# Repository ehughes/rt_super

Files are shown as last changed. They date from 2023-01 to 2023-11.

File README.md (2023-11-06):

# RT685 SuperMonkey- Hardware #

This repo has the PCB design data for the SuperMonkey that is based upon the i.MXRT685 in a VFBGA176 package.  This design was created to show a minimal configuration example of the i.MXRT685 using QSPI flash on FlexSPI port A.    Each PCB revision is in its own folder.  I typically always keep copies of all revisions in one repo so I can have access to multiple CCA versions at one time (instead of branches for each PCB/CCA).   Branches are used for development and merged into master when boards are sent out.

The SuperMonkey is in a prototype state.   Use at your own risk.

### Latest Revision - Navigation ###

The revisions is are PCB Rev B1 and PCB Rev C. 

Rev C is a new formfactor with more pins and integrated OCTAL PSRAM

The design files are in Altium v21 format.

### History/Notes

#### PCB REV B:

- 1st official prototype.   Rev A was dispositioned.

#### PCB REV B:

- 1st official prototype.   Rev A was dispositioned.

#### PCB REV B1:

- Minor Fix to the I2C PMIC Interface
- Font Fixes

#### PCB REV C:

- New Form Factor MK-76 PGA
- No Onboard flash.  Octal PSRA<>

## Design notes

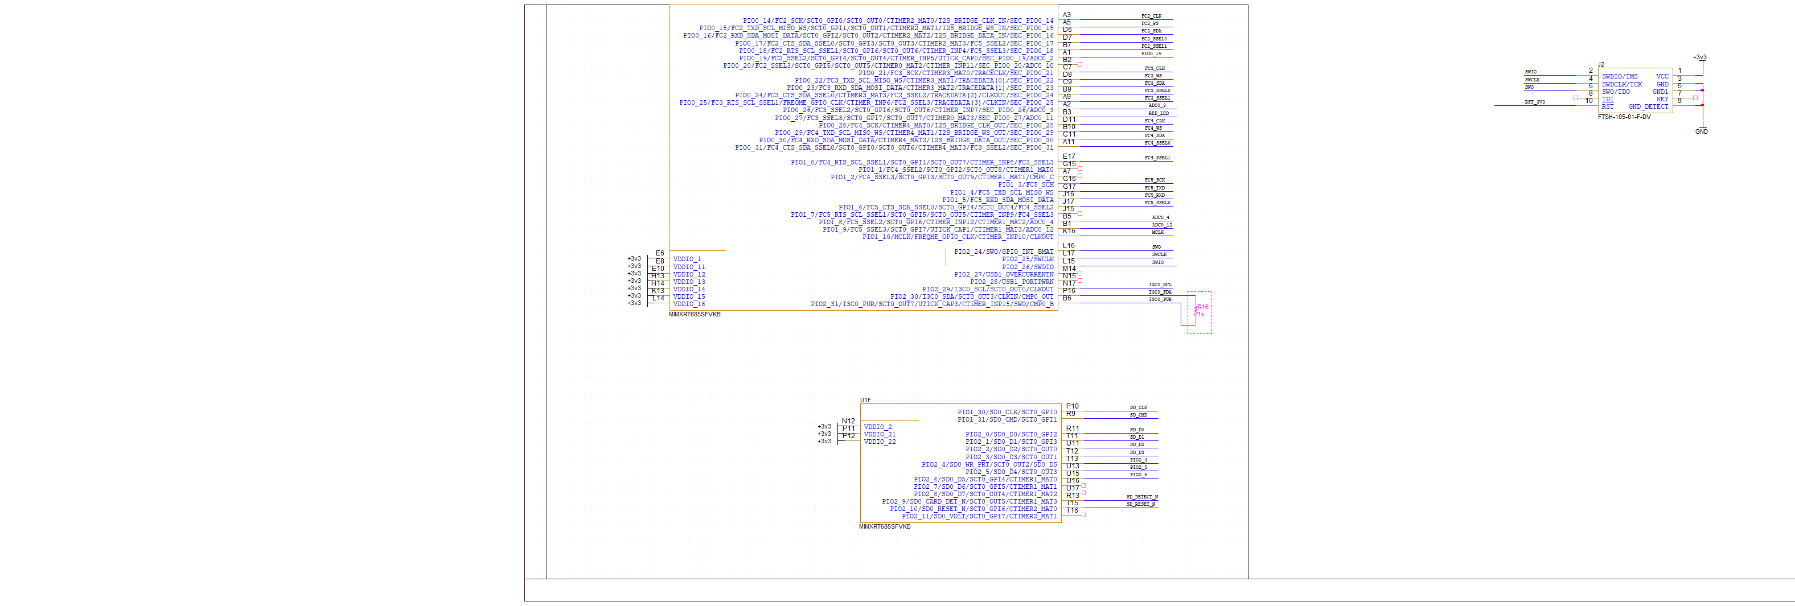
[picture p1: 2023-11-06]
PCB REV C/out/RT_SUPER_C.png

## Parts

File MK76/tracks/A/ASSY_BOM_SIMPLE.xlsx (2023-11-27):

 |  |  |  | Assembly BOM | Field=CCA_PART_NUMBER
 |  |  |  | Rev: | Field=VariantName
 |  |  |  | Description: | Field =PROJECT_TITLE_LINE_1
Column = Fitted | Column = Line # | Column=Quantity | Column=Designator | Column=Description | Column=Manufacturer | Column=Manufacturer Part Number | Column = Substitution Notes

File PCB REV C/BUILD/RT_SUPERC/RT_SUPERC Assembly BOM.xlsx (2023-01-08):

 |  |  |  | Assembly BOM | RT_SUPER
 |  |  |  | Rev: | C
 |  |  |  | Description: | RT_SUPER
Fitted | Line # | Quantity | Designator | Description | Manufacturer | Manufacturer Part Number | Substitution Notes
Fitted | 1 | 3 | C1, C5, C18 | CAP CER 2.2UF 6.3V X7R 0603 | Murata Electronics | GCM188R70J225KE22D | 2.2µF , 6.3V , ±10% , X7R , -55°C ~ 125°C , AEC-Q200 , 0603
Fitted | 2 | 2 | C2, C42 | CAP CER 4.7UF 6.3V X7S 0603 | Murata Electronics | GCJ188C70J475KE02D | 4.7µF , 6.3V , ±10% , X7S , -55°C ~ 125°C , AEC-Q200 , 0603
Fitted | 3 | 1 | C3 | CAP CER 0.47UF 25V X5R 0402 | Murata Electronics | GRT155R61E474KE01D | 0.47µF , 25V , ±10% , X5R , -55°C ~ 85°C , AEC-Q200 , 0402
Fitted | 4 | 3 | C4, C8, C10 | CAP CER 1UF 10V X7S 0402 | Murata Electronics | GCM155C71A105KE38D | 1µF , 10V , ±10% , X7S , -55°C ~ 125°C , AEC-Q200 , 0402
Fitted | 5 | 29 | C6, C12, C13, C14, C15, C16, C17, C20, C21, C22, C23, C24, C25, C26, C27, C28, C29, C30, C31, C32, C33, C34, C35, C36, C37, C38, C39, C40, C41 | Cap Ceramic 0.1uF 6.3VDC X5R 10% SMD 0201 Paper T/R | Yageo | CC0201KRX5R5BB104
Fitted | 6 | 2 | C7, C9 | CAP CER 10UF 10V X5R 0603 | Murata Electronics | GRT188R61A106ME13D | 10µF , 10V , ±20% , X5R , -55°C ~ 85°C , AEC-Q200 , 0603
Fitted | 7 | 2 | C11, C19 | CAP CER 18PF 50V C0G 0402 | TDK Corporation | CGA2B2C0G1H180J050BA | 18pF , 50V , ±5% , C0G, NP0 , -55°C ~ 125°C , AEC-Q200 , 0402
Fitted | 8 | 1 | C43 | CAP CER 0.1UF 16V X7R 0402 | TDK Corporation | CGA2B1X7R1C104K050BC | 0.1µF , 16V , ±10% , X7R , -55°C ~ 125°C , AEC-Q200 , 0402
Fitted | 9 | 2 | C44, C45 | CAP CER 9.5PF 50V C0G/NP0 0402 | Murata Electronics | GCQ1555C1H9R5BB01D | 9.5pF , 50V , ±0.1pF , C0G, NP0 , -55°C ~ 125°C , AEC-Q200 , 0402
Fitted | 10 | 2 | D1, D2 | DIODE SCHOTTKY 30V 1A SOD323 | Diodes Inc | BAT760-7
Fitted | 11 | 1 | D3 | LED 1.6X0.8MM 570NM GRN CLR SMD | Kingbright Corp | APT1608CGCK
Fitted | 12 | 1 | D4 | LED 1.6X0.8MM 630NM RED CLR SMD | Kingbright Corp | APT1608SURCK
Fitted | 13 | 1 | J2 | SAMTEC - FTSH-105-01-F-DV - .050 X .050 | SAMTEC | FTSH-105-01-F-DV
Fitted | 14 | 2 | L2, L3 | Inductor 2.2µH 1.5A | Taiyo Yuden | NRH3012T2R2MN
Fitted | 15 | 1 | R1 | RES 10K OHM 1/10W 1% 0402 SMD | Panasonic Electronic Components | ERJ-2RKF1002X | 10k , ±1% , 0402 , AEC-Q200
Fitted | 16 | 2 | R2, R5 | RES 20K OHM 1/10W 1% 0402 SMD | Panasonic Electronic Components | ERJ-2RKF2002X | 20k , ±1% , 0402 , AEC-Q200
Fitted | 17 | 2 | R3, R4 | RES 2.2K OHM 1/10W 1% 0402 SMD | Panasonic Electronic Components | ERJ-2RKF2201X | 2.2k , ±1% , 0402 , AEC-Q200
Fitted | 18 | 6 | R6, R7, R10, R11, R21, R22 | RES 0.0 OHM 1/10W JUMP 0402 SMD | Panasonic Electronic Components | ERJ-2GE0R00X | 0 , Jumper , 0402 , AEC-Q200
Fitted | 19 | 5 | R8, R9, R12, R13, R14 | RES 100K OHM 1/10W 1% 0402 SMD | Panasonic Electronic Components | ERJ-2RKF1003X | 100k , ±1% , 0402 , AEC-Q200
Not Fitted | 19 | 0 | R15, R17, R18 | RES 100K OHM 1/10W 1% 0402 SMD | Panasonic Electronic Components | ERJ-2RKF1003X | 100k , ±1% , 0402 , AEC-Q200
Fitted | 20 | 3 | R16, R19, R20 | RES 1K OHM 1/10W 1% 0402 SMD | Panasonic Electronic Components | ERJ-2RKF1001X | 1k , ±1% , 0402 , AEC-Q200
Fitted | 21 | 1 | U1 | SOC i.MX ARM Cortex M33 176-Pin VFBGA Tray | NXP Semiconductors | MIMXRT685SFVKB
Fitted | 22 | 1 | U2 | Power Management IC for Low-Power Microcontroller Applications 24-Pin HVQFN | NXP Semiconductors | PCA9420BSAZ
Fitted | 23 | 1 | U3 | IC BUFF NON-INVERT 2.7 V SOT23-5 | Texas Instruments | SN74AUC1G07DBVR
Fitted | 24 | 1 | U4 | TVS DIODE 5.5VWM SOT143B | NXP Semiconductors | PRTR5V0U2X,215
Fitted | 25 | 1 | U6 | 3.3v Double-Data-Rate Octal SPI Xccela PSRAM | AP Memory | APS6408L-3OBM-BA
Fitted | 26 | 1 | X1 | CRYSTAL 32.768KHZ 9PF SMD | NDK | NX3215SA-32.768K-STD-MUA-9
Fitted | 27 | 1 | X2 | CRYSTAL 24.000MHZ 18PF SMD | Abracon Corporation | ABM3-24.000MHZ-B2-T

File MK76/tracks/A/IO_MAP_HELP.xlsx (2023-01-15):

 |  |  |  | ____
 |  |  |  |  | Name | Pin Designator | X1 | Y1 | ObjectKind | Orientation
1 | VREF |  |  |  | VREF | 1 | 0 | 0 | Pin | 0 Degrees
2 | ADC0_8 | PIO0_6 | PIO0_6____ |  | PIO0_6____ADC0_8 | 2 | 0 | -100 | Pin | 0 Degrees
3 | FC0_RXD | PIO0_2 | PIO0_2____ |  | PIO0_2____FC0_RXD | 3 | 0 | -200 | Pin | 0 Degrees
4 | FC0_TXD | PIO0_1 | PIO0_1____ |  | PIO0_1____FC0_TXD | 4 | 0 | -300 | Pin | 0 Degrees
5 | FC0_CLK | PIO0_0 | PIO0_0____ |  | PIO0_0____FC0_CLK | 5 | 0 | -400 | Pin | 0 Degrees
6 | FC0_SSEL0 | PIO0_3 | PIO0_3____ |  | PIO0_3____FC0_SSEL0 | 6 | 0 | -500 | Pin | 0 Degrees
7 | FC0_SSEL1 | PIO0_4 | PIO0_4____ |  | PIO0_4____FC0_SSEL1 | 7 | 0 | -600 | Pin | 0 Degrees
8 | FC1_CLK | PIO0_7 | PIO0_7____ |  | PIO0_7____FC1_CLK | 8 | 0 | -700 | Pin | 0 Degrees
9 | FC1_SSEL0 | PIO0_10 | PIO0_10____ |  | PIO0_10____FC1_SSEL0 | 9 | 0 | -800 | Pin | 0 Degrees
10 | FC1_RXD | PIO0_9 | PIO0_9____ |  | PIO0_9____FC1_RXD | 10 | 0 | -900 | Pin | 0 Degrees
11 | FC1_TXD | PIO0_8 | PIO0_8____ |  | PIO0_8____FC1_TXD | 11 | 0 | -1000 | Pin | 0 Degrees
12 | FC1_SSEL1 | PIO0_11 | PIO0_11____ |  | PIO0_11____FC1_SSEL1 | 12 | 0 | -1100 | Pin | 0 Degrees
13 | HS_SPI_SCK | PIO1_11 | PIO1_11____ |  | PIO1_11____HS_SPI_SCK | 13 | 0 | -1200 | Pin | 0 Degrees
14 | HS_SPI_MISO | PIO1_12 | PIO1_12____ |  | PIO1_12____HS_SPI_MISO | 14 | 0 | -1300 | Pin | 0 Degrees
15 | HS_SPI_MOSI | PIO1_13 | PIO1_13____ |  | PIO1_13____HS_SPI_MOSI | 15 | 0 | -1400 | Pin | 0 Degrees
16 | HS_SPI_SSEL0 | PIO1_14 | PIO1_14____ |  | PIO1_14____HS_SPI_SSEL0 | 16 | 0 | -1500 | Pin | 0 Degrees
17 | ISP0 | PIO1_15 | PIO1_15____ |  | PIO1_15____ISP0 | 17 | 0 | -1600 | Pin | 0 Degrees
18 | ISP1 | PIO1_16 | PIO1_16____ |  | PIO1_16____ISP1 | 18 | 0 | -1700 | Pin | 0 Degrees
19 | ISP2 | PIO1_17 | PIO1_17____ |  | PIO1_17____ISP2 | 19 | 0 | -1800 | Pin | 0 Degrees
20 | FLEXSPI0B_CLK | PIO1_29 | PIO1_29____ |  | PIO1_29____FLEXSPI0B_CLK | 20 | 0 | -1900 | Pin | 0 Degrees
21 | PDM_DATA01 | PIO2_20 | PIO2_20____ |  | PIO2_20____PDM_DATA01 | 21 | 0 | -2000 | Pin | 0 Degrees
22 | PDM_CLK01 | PIO2_16 | PIO2_16____ |  | PIO2_16____PDM_CLK01 | 22 | 0 | -2100 | Pin | 0 Degrees
23 | PDM_DATA23 | PIO2_21 | PIO2_21____ |  | PIO2_21____PDM_DATA23 | 23 | 0 | -2200 | Pin | 0 Degrees
24 | PDM_CLK23 | PIO2_17 | PIO2_17____ |  | PIO2_17____PDM_CLK23 | 24 | 0 | -2300 | Pin | 0 Degrees
25 | PDM_DATA45 | PIO2_22 | PIO2_22____ |  | PIO2_22____PDM_DATA45 | 25 | 0 | -2400 | Pin | 0 Degrees
26 | PDM_CLK45 | PIO2_18 | PIO2_18____ |  | PIO2_18____PDM_CLK45 | 26 | 0 | -2500 | Pin | 0 Degrees
27 | PDM_DATA67 | PIO2_23 | PIO2_23____ |  | PIO2_23____PDM_DATA67 | 27 | 0 | -2600 | Pin | 0 Degrees
28 | PDM_CLK67 | PIO2_19 | PIO2_19____ |  | PIO2_19____PDM_CLK67 | 28 | 0 | -2700 | Pin | 0 Degrees
29 | SD_CMD |  |  |  | SD_CMD | 29 | 0 | -2800 | Pin | 0 Degrees
30 | SD_D0 |  |  |  | SD_D0 | 30 | 0 | -2900 | Pin | 0 Degrees
31 | SD_D1 |  |  |  | SD_D1 | 31 | 0 | -3000 | Pin | 0 Degrees
32 | SD_D2 |  |  |  | SD_D2 | 32 | 0 | -3100 | Pin | 0 Degrees
33 | SD_D3 |  |  |  | SD_D3 | 33 | 0 | -3200 | Pin | 0 Degrees
34 | SD_CLK |  |  |  | SD_CLK | 34 | 0 | -3300 | Pin | 0 Degrees
35 | SD_RESET_N | PIO2_10 | PIO2_10____ |  | PIO2_10____SD_RESET_N | 35 | 0 | -3400 | Pin | 0 Degrees
36 | SD_DETECT_N | PIO2_9 | PIO2_9____ |  | PIO2_9____SD_DETECT_N | 36 | 0 | -3500 | Pin | 0 Degrees
37 | PIO2_4 |  |  |  | PIO2_4 | 37 | 0 | -3600 | Pin | 0 Degrees
38 | PIO2_5 |  |  |  | PIO2_5 | 38 | 0 | -3700 | Pin | 0 Degrees
39 | PIO2_6 |  |  |  | PIO2_6 | 39 | 3000 | 0 | Pin | 0 Degrees
40 | I3C0_SDA |  |  |  | I3C0_SDA | 40 | 3000 | -100 | Pin | 0 Degrees
41 | I3C0_SCL |  |  |  | I3C0_SCL | 41 | 3000 | -200 | Pin | 0 Degrees
42 | FC5_RXD | PIO1_5 | PIO1_5____ |  | PIO1_5____FC5_RXD | 42 | 3000 | -300 | Pin | 0 Degrees
43 | DM_MCU |  |  |  | DM_MCU | 43 | 3000 | -400 | Pin | 0 Degrees
44 | FC5_SSEL0 | PIO1_6 | PIO1_6____ |  | PIO1_6____FC5_SSEL0 | 44 | 3000 | -500 | Pin | 0 Degrees
45 | DP_MCU |  |  |  | DP_MCU | 45 | 3000 | -600 | Pin | 0 Degrees
46 | FC5_TXD | PIO1_4 | PIO1_4____ |  | PIO1_4____FC5_TXD | 46 | 3000 | -700 | Pin | 0 Degrees
47 | FC5_SCK | PIO1_3 | PIO1_3____ |  | PIO1_3____FC5_SCK | 47 | 3000 | -800 | Pin | 0 Degrees
48 | MCLK | PIO1_10 | PIO1_10____ |  | PIO1_10____MCLK | 48 | 3000 | -900 | Pin | 0 Degrees
49 | RST_3V3 |  |  |  | RST_3V3 | 49 | 3000 | -1000 | Pin | 0 Degrees
50 | +3v3 |  |  |  | +3v3 | 50 | 3000 | -1100 | Pin | 0 Degrees
51 | TEMP_SENSE |  |  |  | TEMP_SENSE | 51 | 3000 | -1200 | Pin | 0 Degrees
52 | PMIC_ON |  |  |  | PMIC_ON | 52 | 3000 | -1300 | Pin | 0 Degrees
53 | +VBATT_BU |  |  |  | +VBATT_BU | 53 | 3000 | -1400 | Pin | 0 Degrees
54 | GND |  |  |  | GND | 54 | 3000 | -1500 | Pin | 0 Degrees
55 | +5vUSB |  |  |  | +5vUSB | 55 | 3000 | -1600 | Pin | 0 Degrees
56 | +VBATT |  |  |  | +VBATT | 56 | 3000 | -1700 | Pin | 0 Degrees
57 | +VIN |  |  |  | +VIN | 57 | 3000 | -1800 | Pin | 0 Degrees
58 | FC2_SSEL0 | PIO0_17 | PIO0_17____ |  | PIO0_17____FC2_SSEL0 | 58 | 3000 | -1900 | Pin | 0 Degrees
59 | FC2_SDA | PIO0_16 | PIO0_16____ |  | PIO0_16____FC2_SDA | 59 | 3000 | -2000 | Pin | 0 Degrees
60 | FC2_SSEL1 | PIO0_18 | PIO0_18____ |  | PIO0_18____FC2_SSEL1 | 60 | 3000 | -2100 | Pin | 0 Degrees
61 | FC2_WS | PIO0_15 | PIO0_15____ |  | PIO0_15____FC2_WS | 61 | 3000 | -2200 | Pin | 0 Degrees
62 | FC2_CLK | PIO0_14 | PIO0_14____ |  | PIO0_14____FC2_CLK | 62 | 3000 | -2300 | Pin | 0 Degrees
63 | FC4_SSEL1 | PIO1_0 | PIO1_0____ |  | PIO1_0____FC4_SSEL1 | 63 | 3000 | -2400 | Pin | 0 Degrees
64 | FC4_CLK | PIO0_28 | PIO0_28____ |  | PIO0_28____FC4_CLK | 64 | 3000 | -2500 | Pin | 0 Degrees
65 | FC4_SDA | PIO0_30 | PIO0_30____ |  | PIO0_30____FC4_SDA | 65 | 3000 | -2600 | Pin | 0 Degrees
66 | FC4_SSEL0 | PIO0_31 | PIO0_31____ |  | PIO0_31____FC4_SSEL0 | 66 | 3000 | -2700 | Pin | 0 Degrees
67 | FC4_WS | PIO0_29 | PIO0_29____ |  | PIO0_29____FC4_WS | 67 | 3000 | -2800 | Pin | 0 Degrees
68 | FC3_SSEL0 | PIO0_24 | PIO0_24____ |  | PIO0_24____FC3_SSEL0 | 68 | 3000 | -2900 | Pin | 0 Degrees
69 | FC3_SSEL1 | PIO0_25 | PIO0_25____ |  | PIO0_25____FC3_SSEL1 | 69 | 3000 | -3000 | Pin | 0 Degrees
70 | FC3_SDA | PIO0_23 | PIO0_23____ |  | PIO0_23____FC3_SDA | 70 | 3000 | -3100 | Pin | 0 Degrees
71 | FC3_WS | PIO0_22 | PIO0_22____ |  | PIO0_22____FC3_WS | 71 | 3000 | -3200 | Pin | 0 Degrees
72 | FC3_CLK | PIO0_21 | PIO0_21____ |  | PIO0_21____FC3_CLK | 72 | 3000 | -3300 | Pin | 0 Degrees
73 | ADC0_4 | PIO1_8 | PIO1_8____ |  | PIO1_8____ADC0_4 | 73 | 3000 | -3400 | Pin | 0 Degrees
74 | ADC0_1 | PIO0_12 | PIO0_12____ |  | PIO0_12____ADC0_1 | 74 | 3000 | -3500 | Pin | 0 Degrees
75 | ADC0_3 | PIO0_27 | PIO0_27____ |  | PIO0_27____ADC0_3 | 75 | 3000 | -3600 | Pin | 0 Degrees
76 | ADC0_12 | PIO1_9 | PIO1_9____ |  | PIO1_9____ADC0_12 | 76 | 3000 | -3700 | Pin | 0 Degrees

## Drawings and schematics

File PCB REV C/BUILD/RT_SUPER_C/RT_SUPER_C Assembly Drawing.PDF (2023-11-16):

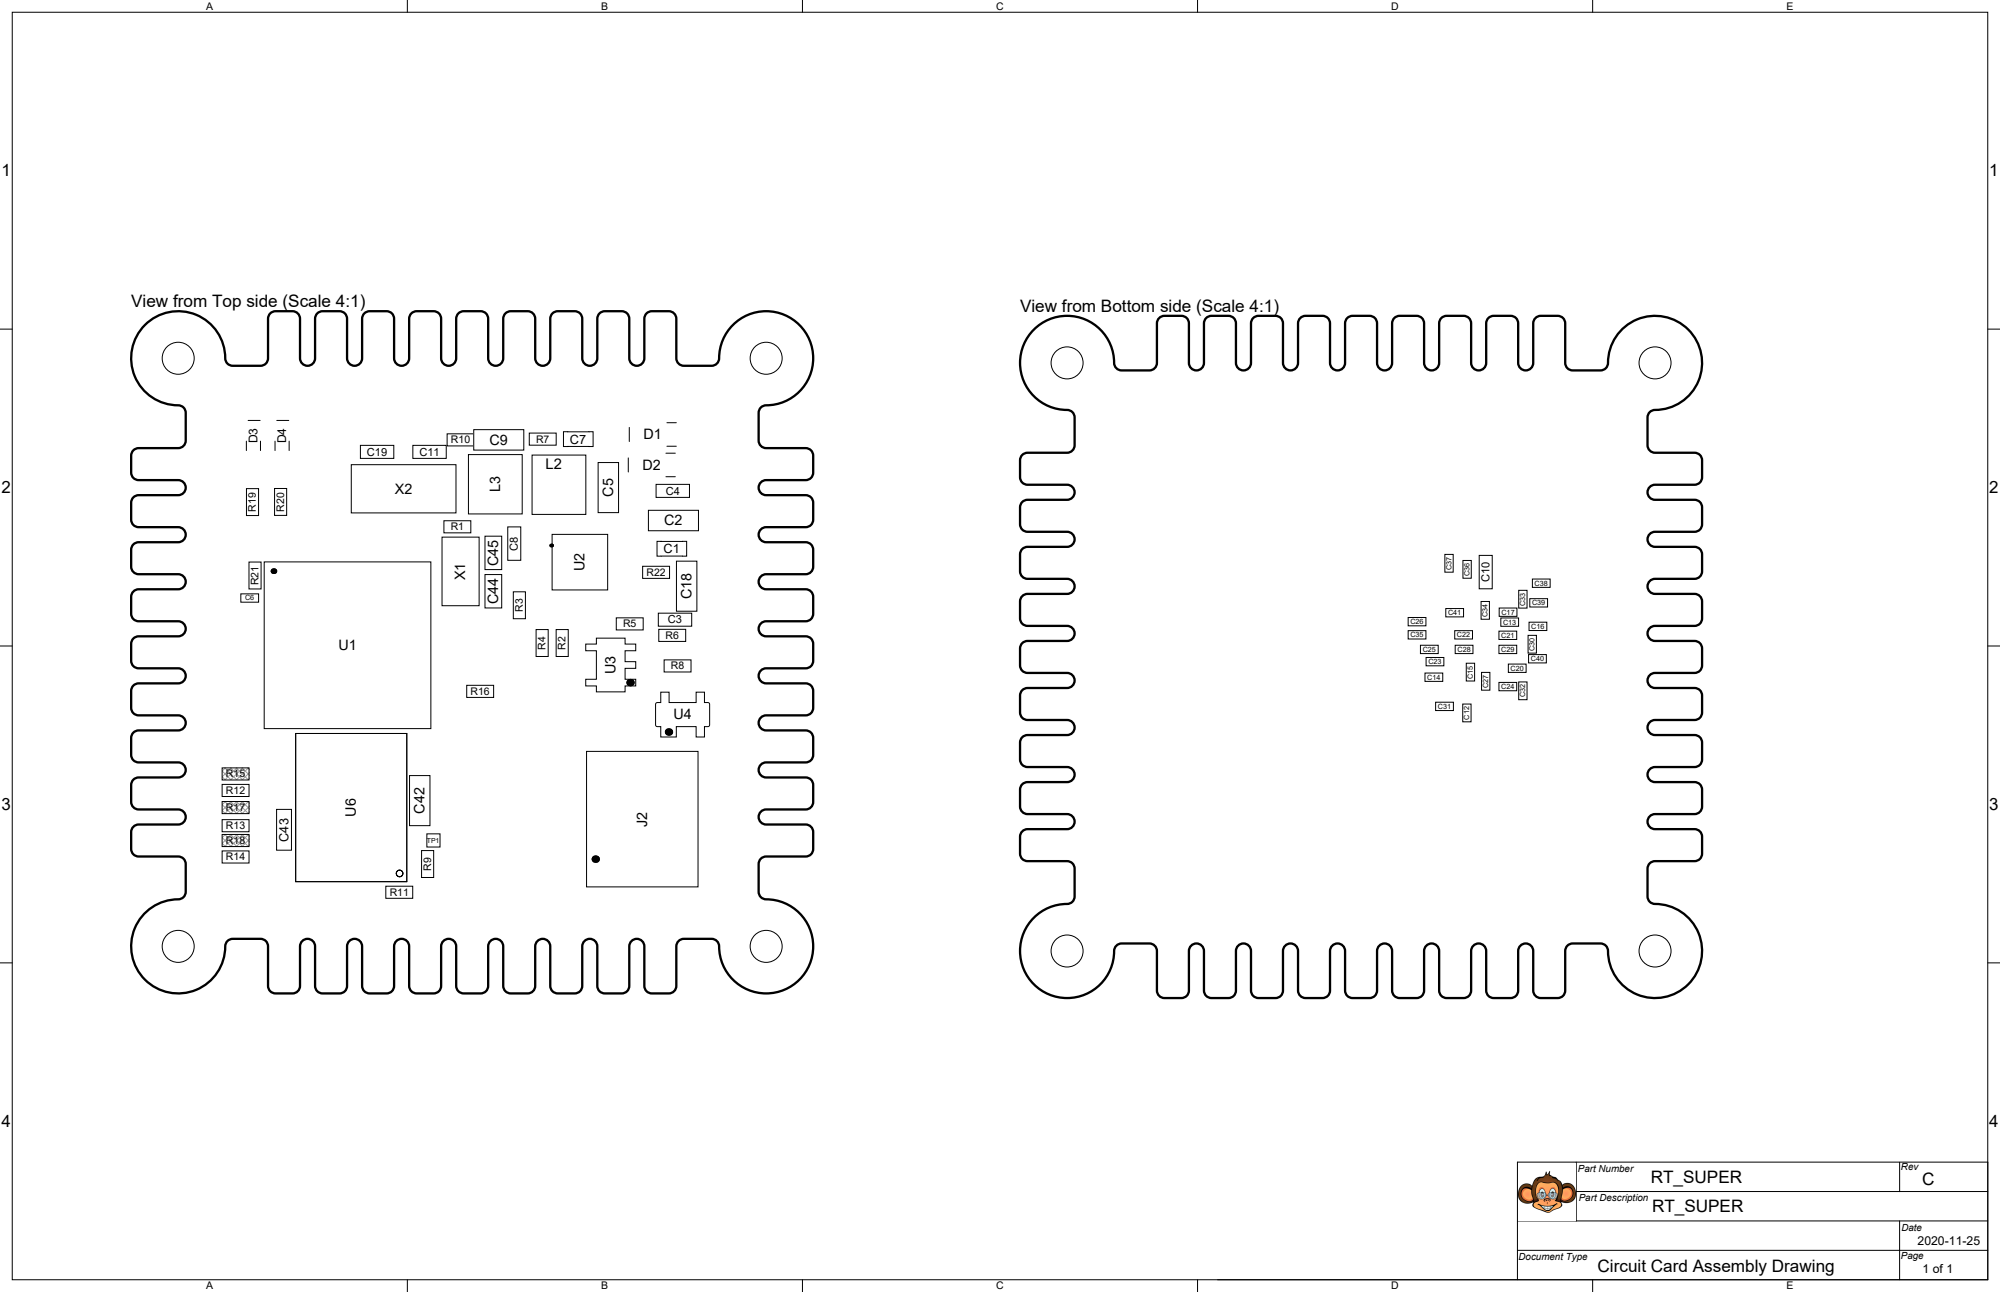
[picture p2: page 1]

View from Top side (Scale 4:1)

View from Bottom side (Scale 4:1)

Circuit Card Assembly Drawing

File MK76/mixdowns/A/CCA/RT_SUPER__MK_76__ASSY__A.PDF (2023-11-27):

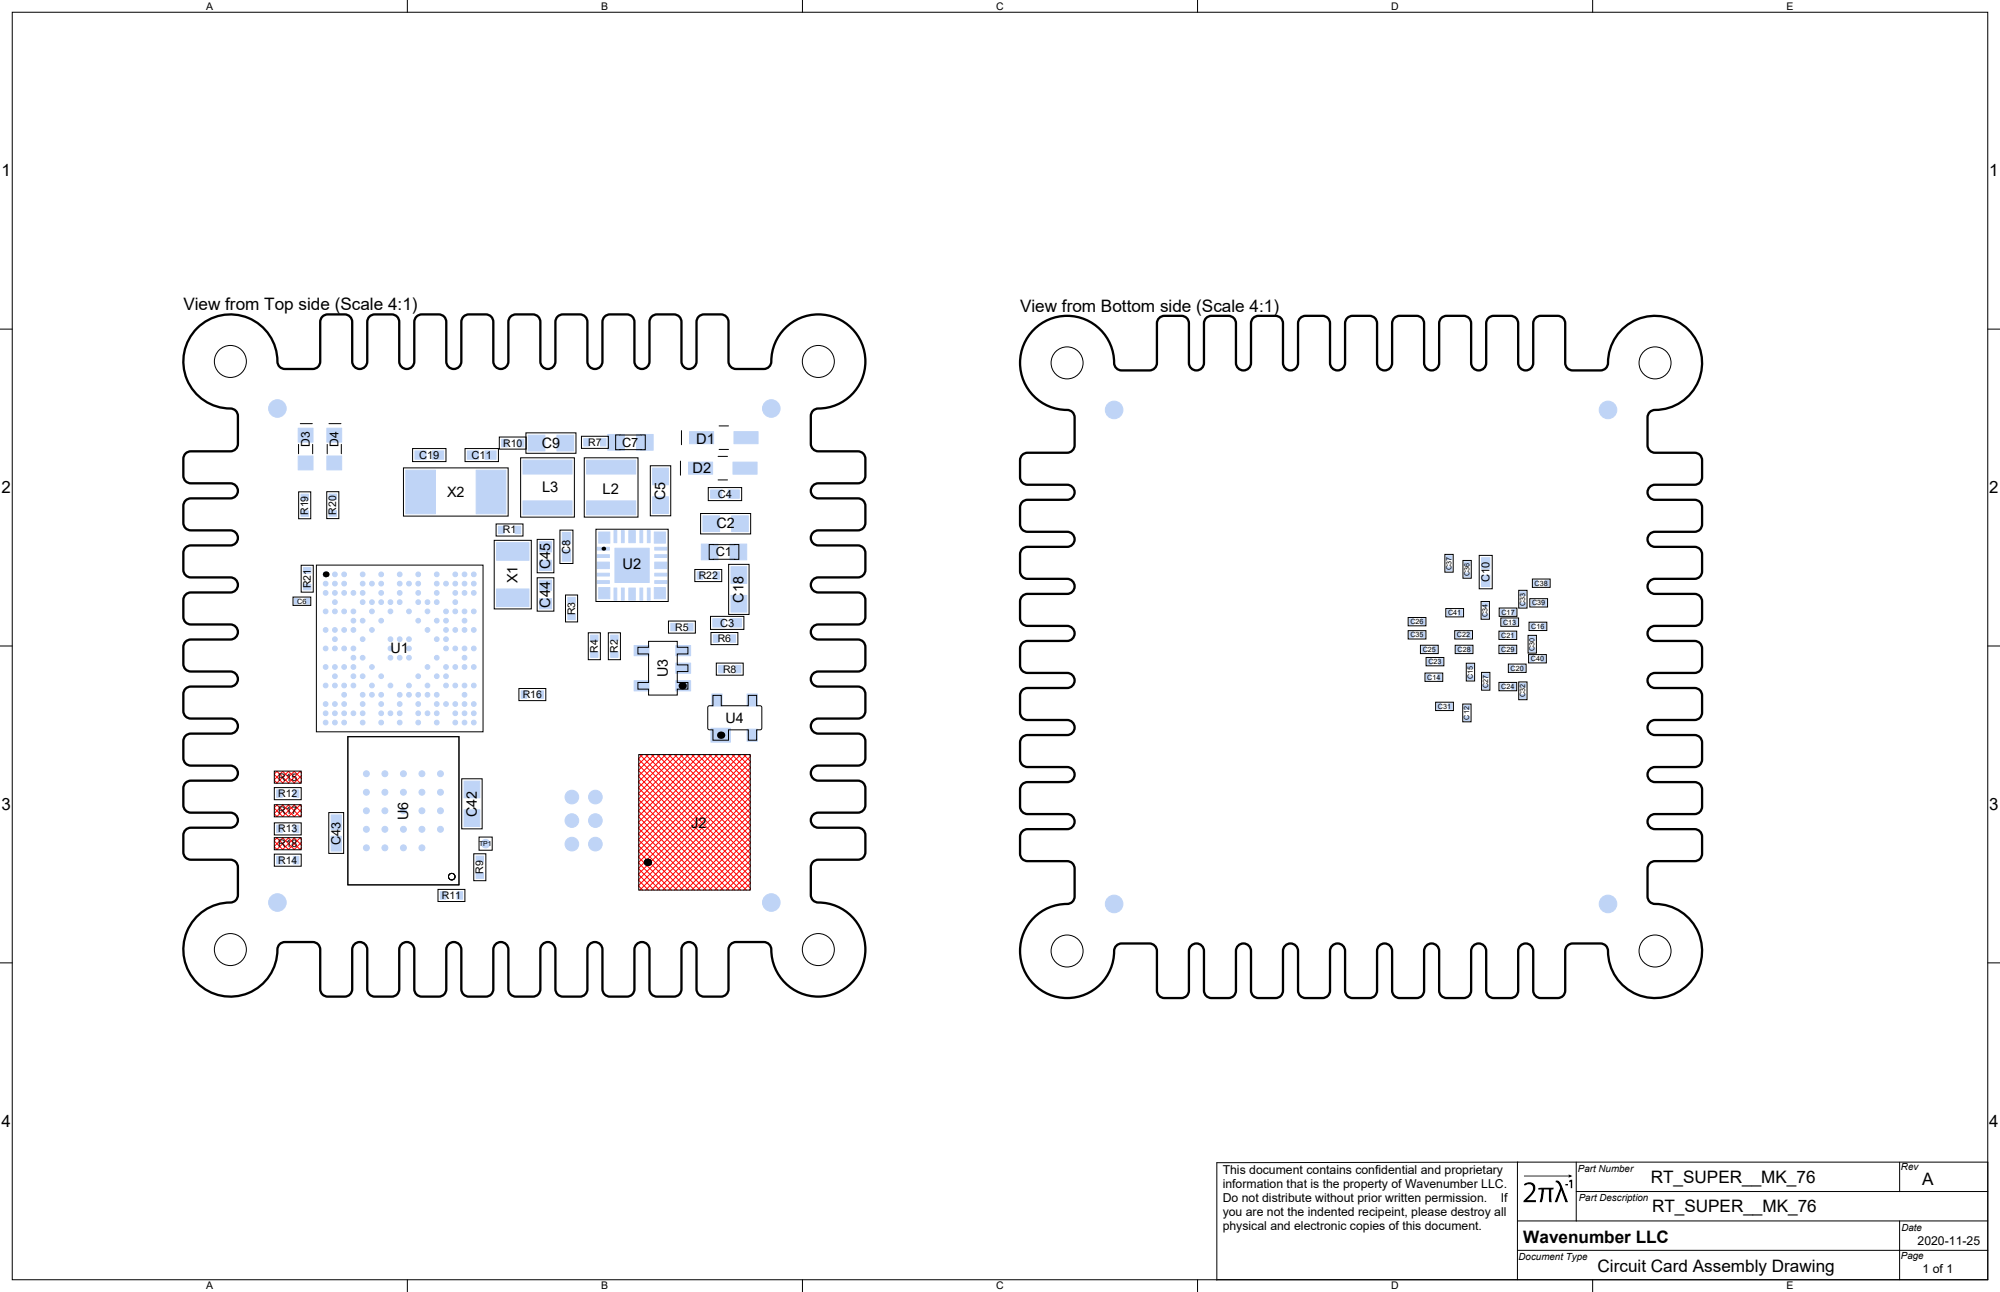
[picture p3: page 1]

View from Top side (Scale 4:1)

View from Bottom side (Scale 4:1)

This document contains confidential and proprietary
information that is the property of Wavenumber LLC.
Do not distribute without prior written permission. If
you are not the indented recipeint, please destroy all
physical and electronic copies of this document.

Wavenumber LLC | Date 2020-11-25

Document Type Circuit Card Assembly Drawing | Page

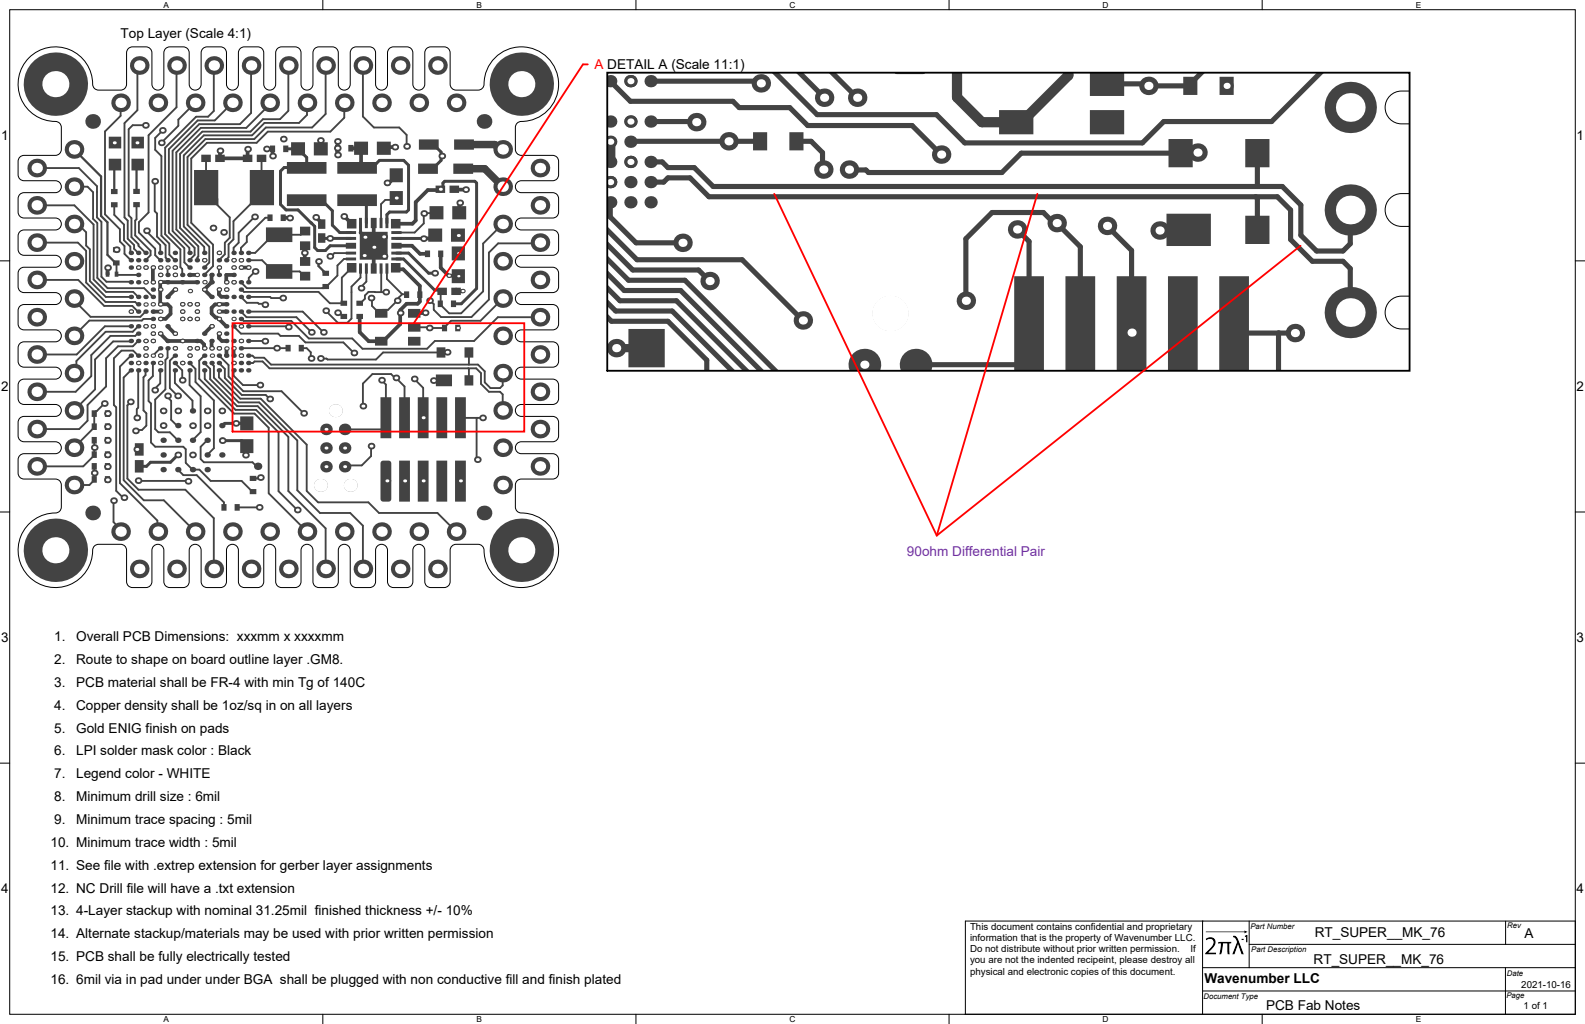
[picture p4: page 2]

1. Overall PCB Dimensions: xxxmm x xxxxmm
2. Route to shape on board outline layer .GM8.
3. PCB material shall be FR-4 with min Tg of 140C
4. Copper density shall be 1oz/sq in on all layers
5. Gold ENIG finish on pads
6. LPI solder mask color : Black
7. Legend color - WHITE
8. Minimum drill size : 6mil
9. Minimum trace spacing : 5mil
10. Minimum trace width : 5mil
11. See file with .extrep extension for gerber layer assignments
12. NC Drill file will have a .txt extension
13. 4-Layer stackup with nominal 31.25mil finished thickness +/- 10%
14. Alternate stackup/materials may be used with prior written permission
15. PCB shall be fully electrically tested
16. 6mil via in pad under under BGA shall be plugged with non conductive fill and finish plated

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

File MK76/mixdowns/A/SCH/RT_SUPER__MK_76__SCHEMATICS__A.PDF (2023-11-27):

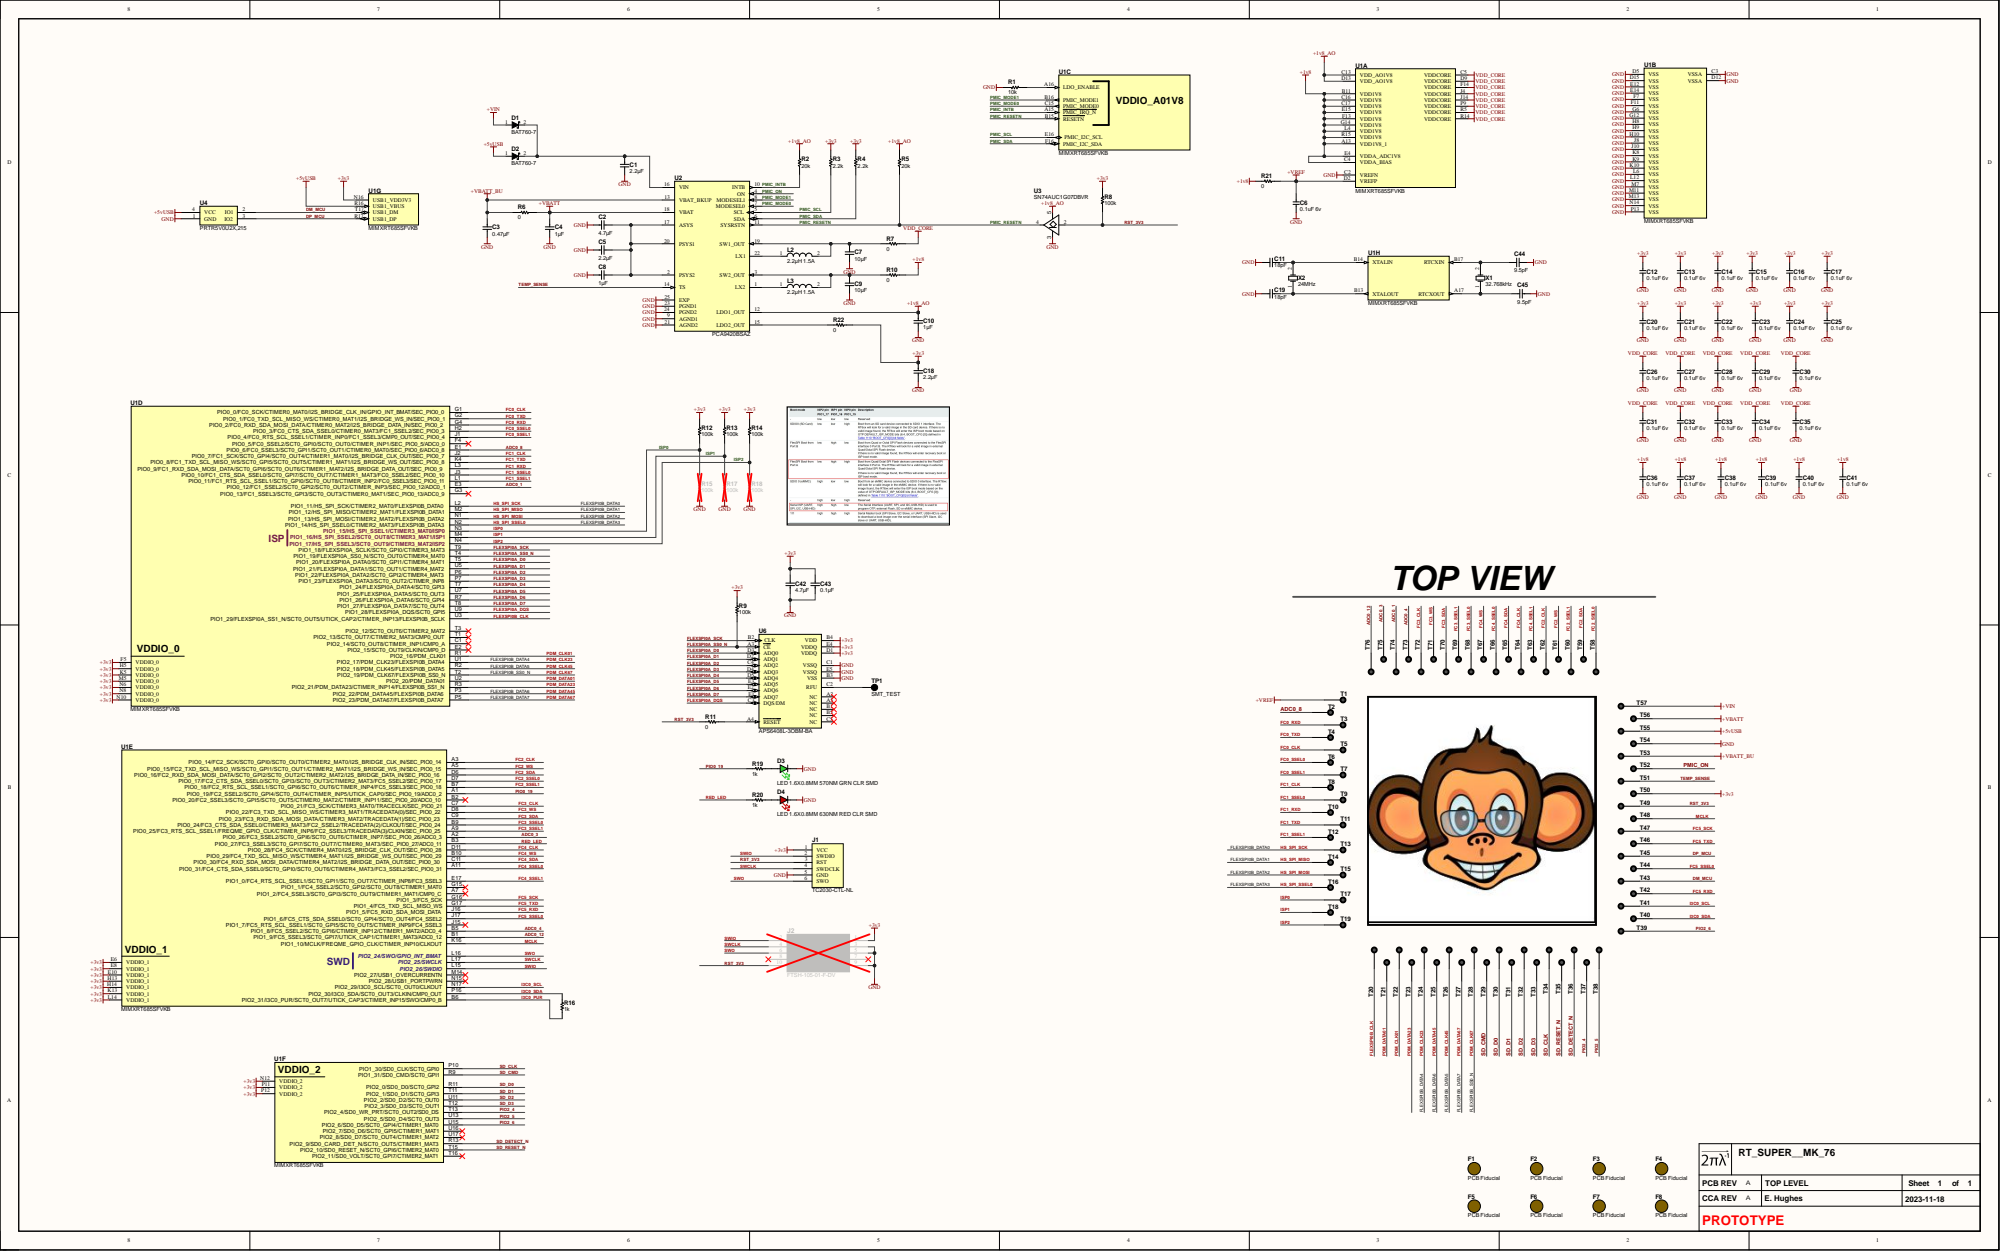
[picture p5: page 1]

PC B REV A | TO P LEVEL | Shee t 1 o f 1

C C A REV A | E. Hughes | 2023-11-1 8

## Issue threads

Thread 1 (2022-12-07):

Questions the hardware design

rayc345, 2022-12-07:
Hello, Eli H. Thank you very much for sharing your design about the IMXRT685 DSP chip!
I'm interested in this chip recently, I found your design and want to take it as one of my references.
About the circuit, I think you made a small mistake in the pull-up of PMIC I2C, the two resistors should be connected to 3.3V since the VDDIO_1 is 3.3V in this design.
Also I have some puzzles about the USB. According to UM11147, two termination resisters of 45 Ohms are inside the chip. Why did the design use two 33 Ohms resistor? In IMXRT685-AUD, these two resistor do not exist.
Best regards. Ray Zhang.

ehughes, 2022-12-07:
Hello Ray.

Thanks for taking the time to report your findings.       Yes, the I.MXRT685 is a nice chip.   There is a lot of availability and it is very powerful!

1.)  Yes, you are correct.   The Rev A design (which is not on Github) used 1.8v IO for VDDIO1.  I forgot to change it.     It might work as is w/ the 1.8v pull-up.

2.)   Sorrry for the confusion here.   Those should be labeled as Zero ohm.  I typically have pads on USB "just in case" and need to make adjustments.

I'll make a note on the schematic about 1 & 2 and push up the changes.

Side note.... This design did not include any connections for "recovery" boot.    There is a mode where you can boot to RAM via a 1-bit NOR SPI if other boot sources fail (such as the SD card).     I designed the SuperMonkey XIP on the FlexSPI but like to to exectute everything from internal RAM.     The Recovery boot is simple add.

Let me know your your own design goes.   I'll be working on another RT685 design again soon.

ehughes, 2022-12-07:
Also,   something else to consider.     This design uses 0201 capacitors underneath the chip for decoupling.  I think  0402's could be used of twice the value (.22uF)  and use half as many.        It would make routing easier.

rayc345, 2022-12-08:
Thank you for your explaination. Currently, I'v finished designing the schematic and PCB. Now I'm waiting for the arrival of the chip and checking the designing concurrently. The PCB manufacturing and SMT is quite expensive, about  $214 for 5 PCBA pieces( including material costs) so I want to succeed at the first time.

On the top of PCB, there are the RT685 main IC, power managment and connectors.
On the bottom, bypass capacitors, Reset control and ESD protection diodes are placed.
The top copper layer is used to route high-speed signal( HS SPI and USB), power managment, XTAL.
Inner 1 layer is ground plane and is not shown in the picture below.
Inner 2 layer is used to route I2S signals and PMIC communicayion signals.
Bottom layer is used for power lines.
One serial port is connected to the SWD header to allow communication to PC through a bridge.
Four I2S( in two of them only DATA signal is routed out) connected to the header, allowing audio/baseband signal input from another board.

For the past several months, I'v been able to use MATLAB/Simulink as the simulation platform for several Cortex-M MCUs so I can use Simulink for build up my algorithm and get it executed, verified or profiled by a single click. I would like to extend this software platform to the HiFi4 DSP so I can process audio/radio signals more efficiently. That's why I want to use RT685.
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

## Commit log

2021-10-16 1st add
    [ASSY_BOM_SIMPLE.xlsx, RT_SUPER_B.PrjPcb, RT_SUPER_B.SchDoc]
2021-10-16 fixed typo on QSPI flash memory part number
    [RT_SUPER_B.PrjPcb, RT_SUPER_B.SchDoc]
2021-10-16 fixed pin numbers on schematic for better readability
    [RT_SUPER_B.SchDoc]
2022-02-09 adding in KiCad Import
    [0402_0.55mm.STEP, 0603_0.90mm.STEP, 0805_1.45mm.STEP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]
2022-12-07 added schematic bug notes
    [RT_SUPER_B.PrjPcb, RT_SUPER_B.SchDoc]
2022-12-27 working on C....
    [0402_0.55mm.STEP, 0603_0.90mm.STEP, 0805_1.45mm.STEP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]
2023-01-03 reworking C
    [0402_0.55mm.STEP, 0603_0.90mm.STEP, 0805_1.45mm.STEP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]
2023-01-05 route update
    [RT_SUPER_C.PCBdoc, RT_SUPER_C.PrjPcb, RT_SUPER_C.SchDoc]
2023-01-05 route up
    [RT_SUPER_C.PCBdoc, RT_SUPER_C.SchDoc]
2023-01-06 dev update
    [RT_SUPER_C.PCBdoc, RT_SUPER_C.SchDoc]
2023-01-08 rev C for budgetary quote
    [RT_SUPERC Assembly BOM.xlsx, RT_SUPER_C Pick-Place.csv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]
2023-11-06 cleaning up...
    [0402_0.55mm.STEP, 0603_0.90mm.STEP, 0805_1.45mm.STEP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]
2023-11-16 seeding the host
    [ADC_DAC.SchDoc, ASSY_BOM_SIMPLE.xlsx, AU0005.SCHLIB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]
2023-11-19 outjob updates
    [MK76_HOST__A.PrjPcb, RT_SUPER__MK76__A.PrjPcb, RT_SUPER__MK76__A.SchDoc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]
2023-11-19 working on outjob
    [RT_SUPER__MK_76_A.GBL, RT_SUPER__MK_76_A.GBO, RT_SUPER__MK_76_A.GBP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]
2023-11-19 outjob update
    [0402_0.55mm.STEP, 0603_0.90mm.STEP, ASSY_BOM_SIMPLE.xlsx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]
2023-11-28 updated SM module IO. Bad PIO number on ADC0_3
    [MK76_HOST__A.PrjPcb, MK76_HOST__A.SchDoc]
2023-11-29 Adding note that FC5 connection to LCD is incorrect. TXD is SPI MISO, not MOSI
    [MK76_HOST__A.SchDoc]
